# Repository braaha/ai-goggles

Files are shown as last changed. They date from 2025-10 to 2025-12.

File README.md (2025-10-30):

AI Goggles to Understand Influences on Well-being with Life-changing Injury or Pathology

Team Members:

Team Member #1: Cooper Bush – Computer Science
Team Member #2: AJ Aneja – Mechanical Engineering
Team Member #3: Junho Ha – Mechanical Engineering
Team Member #4: Braah Mustafa – Computer Engineering

Fast-Forward Summary:

The prototype we developed is AI goggles to help monitor individuals with neurobehavioral injury. The goggles help us to understand factors in daily life that impact people recovering from spinal injury, strokes, and substance use. The glasses work by recording visual and audio data, and potentially eye tracking. Our prototypes record data through cameras and sensors attached to the frame. The data is then sent to a mobile app that securely transmits the data to a server that uses AI to analyze it.

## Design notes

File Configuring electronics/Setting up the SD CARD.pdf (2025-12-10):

How To Set Up the SD Card With Raspberry Pi Imager:

### 1. Download Raspberry Pi Imager

Go to this site and download Raspberry Pi Imager:

https://www.raspberrypi.com/software/

Install it like a regular app. Nothing special.

### 2. Put the SD Card in Your Laptop

Take the microSD card out of the Pi
put it into the SD card adapter/or sd card reader
then plug the adapter into your laptop.

If your laptop doesn’t have an SD slot, use a USB SD card reader.

### 3. Open Raspberry Pi Imager

When it opens you’ll see three options:

- Choose Device
- Choose OS
- Choose Storage

This is where you pick everything the Pi needs.

### 4. Choose the Device

Click “Choose Device” and select:

Raspberry Pi Zero 2 W

### 5. Choose the Operating System

Click “Choose OS” and pick:

Raspberry Pi OS Lite (32-bit)

This is the version without the desktop. That’s what we used for this project because it runs faster on the small Pi.

### 6. Choose the Storage

Click “Choose Storage” and select the SD card you plugged in.

Just double check you’re selecting the SD card and not another hard drive. (It will erase whatever you choose.)

### 7. Click “Next”

It will ask if you want to edit settings.

Click Yes.

### 8. Fill Out the Settings

This part matters.

A. Set the username and password

Use:

- Username: pi
- Password: (whatever you want)
B. Wi-Fi setup (optional but helpful)

Type in:

- Wi-Fi name
- Wi-Fi password
- Country

This makes the Pi auto-connect when it turns on.

C. Enable SSH (optional)

Turn on SSH if you want to connect to the Pi from your laptop later.

### 9. Click Save → Write

It will erase the SD card and reload the operating system.

When it finishes, eject the SD card like normal.

### 10. Put the SD Card Back Into the Pi

Now the Pi will boot as if it’s brand new.

After that, you still need to put the ai-goggles project folder back on the SD card. You can drag and drop it by plugging the SD card into your laptop again, or by plugging the Pi into your laptop and opening the Pi’s storage.

If something really messed up the Pi, re-imaging is usually the fastest way to fix it.

# If the Pi Won’t Connect to Wi-Fi

Sometimes the Wi-Fi just refuses to connect, and it’s not your fault. Here are things to check:

- Make sure the Wi-Fi you’re using has a normal password. If it makes you log in on a webpage after connecting, the Pi won’t work with that.
- Some networks need both a username and password (like campus or workplace Wi-Fi). The Pi can’t join those automatically.
- Check the Wi-Fi name (SSID). If it has spaces, weird symbols, emojis, or punctuation, the Pi might not like it. Even stuff like “!” or “#” can cause problems.
- Re-enter the Wi-Fi password in Raspberry Pi Imager. Typos happen way more than you’d think.
- When you filled out the Wi-Fi settings in Imager, make sure you chose the right country.
- If all else fails, try connecting the Pi to something simple like your phone’s hotspot just to see if it works.
- And if nothing fixes it… honestly just try re-imaging the SD card again.

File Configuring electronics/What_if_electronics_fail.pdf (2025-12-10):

# What To Do If Something Stops Working

This is just a simple guide to try before replacing any component. A lot of problems are small stuff like a loose wire or the Pi acting up.

## If the microphone stops working

Make sure the mic wires did't come loose from the Pi. They pop out easier than you think.

Check if the Pi even sees the mic:

arecord -l

Restart the Pi and try again, sometimes that actually fixes it.

Run the mic test script (test_mic.py) if you want to double check the audio setup. Also check the audio libraries because if one is missing it wont record at all.

If none of this helps the mic might actually be dead and you will probably need to replace it.

## If the camera stops working

First thing always check the ribbon cable. Make sure it's pushed in fully on both sides. Even a tiny bit loose will break it.

Look at the ribbon to see if it's bent too sharp or damaged. These cables are kinda sensitive.

Restart the Pi and try recording again.

Run the camera test script (test_camera.py). If that script errors out then the Pi is not detecting the camera so its usually the ribbon cable or the camera itself.

## If the Pi wont turn on

Make sure the battery actually has charge. Sometimes it looks plugged in but the battery is empty.

Try a different micro usb cable. Some cables only charge they dont do data and can mess stuff up.

Try powering the Pi from a wall outlet just to test it. If it turns on there then the battery or cable was the issue.

Take the SD card out and put it back in so its seated right.

If it still wont power on then the SD card might be corrupted and you prob need to re image it.

## If the Pi freezes or wont record

Restart the Pi (yeah I know but it works most of the time)

Check the SD card space. If it is full or close to full the recording scripts will freeze.

Try running the script again after a reboot.

Run a simple test script for camera or mic to see if those still work. If one of them fails that's the reason the recording freezes.

Sometimes the SD card is just slow or corrupted and needs a re image.

## If WiFi wont connect

Make sure the WiFi network uses a normal password. If it needs a username and password (like school wifi) the Pi cant join that by default.

Check the WiFi name. If it has weird symbols or like spaces sometimes that causes issues.

Try typing the WiFi name and password again in Raspberry Pi Imager to make sure it wasn't just a typo.

Make sure the correct country was picked when setting up wifi in the imager. If it's set wrong the wifi wont work at all.

Try connecting the Pi to a hotspot from your phone just to see if the Pi wifi is working.

If it still wont connect you can re image the SD card and set the wifi again.

## If SD card errors happen

Copy anything important off the card onto your laptop first.

Re image the SD card using Raspberry Pi Imager.

Put the project folder back onto the SD card after imaging.

Put the SD card back into the Pi and try again.

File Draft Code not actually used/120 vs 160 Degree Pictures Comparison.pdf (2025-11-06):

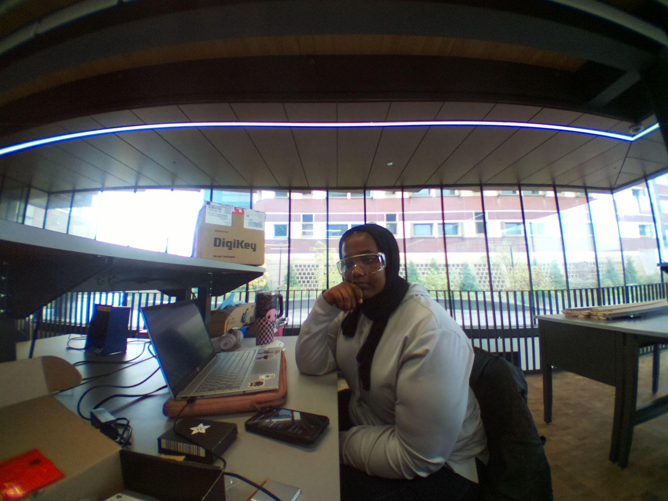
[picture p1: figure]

Zero Spy Camera for Raspberry Pi - 160 Degree

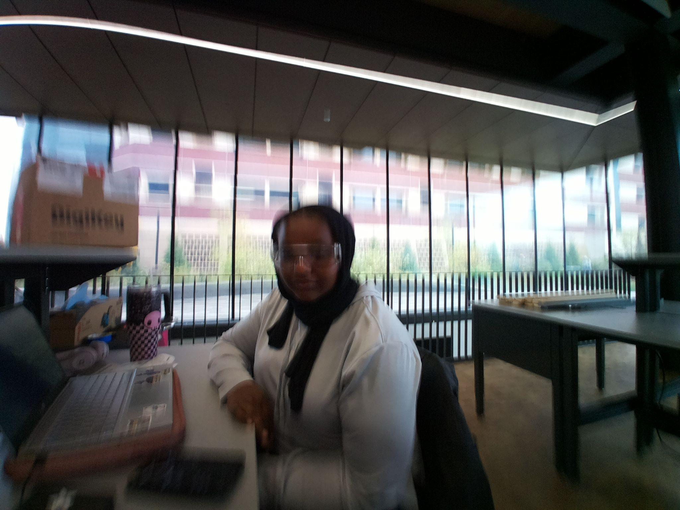
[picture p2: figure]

Zero Spy Camera for Raspberry Pi - 120 Degree

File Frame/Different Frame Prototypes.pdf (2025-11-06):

Appendix A - Concept Generation Models

Drawing Titles | Drawings

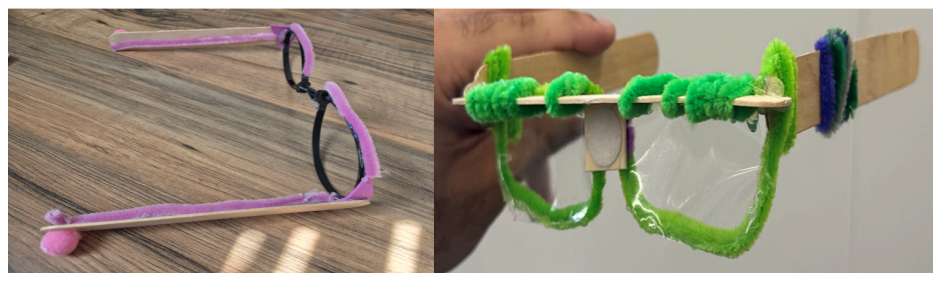
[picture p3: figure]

Prototype 1 (P1)

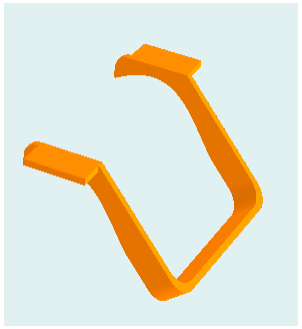
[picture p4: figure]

Prototype 2 (P2)

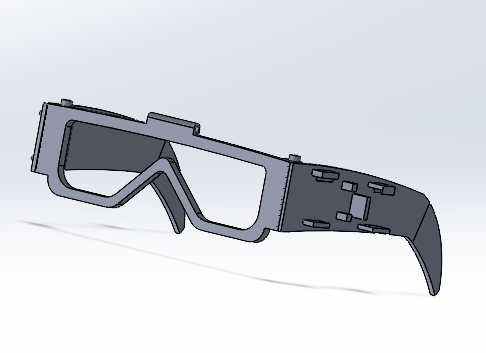
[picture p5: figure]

Prototype 3 (P3)

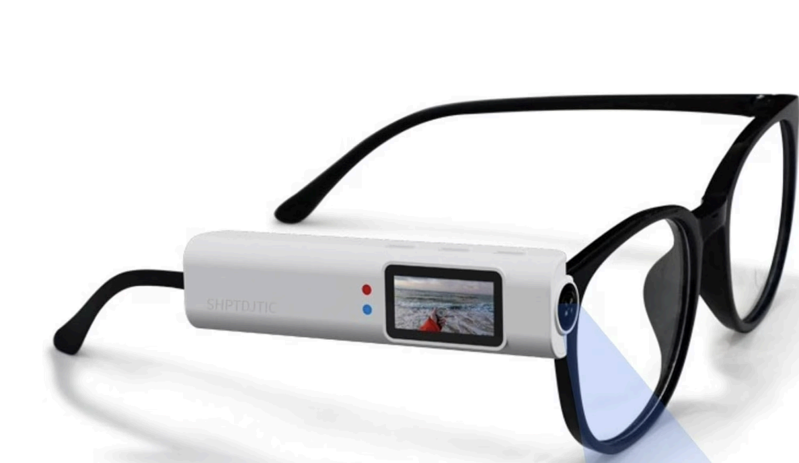
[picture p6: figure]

Reference Prototype (RP)

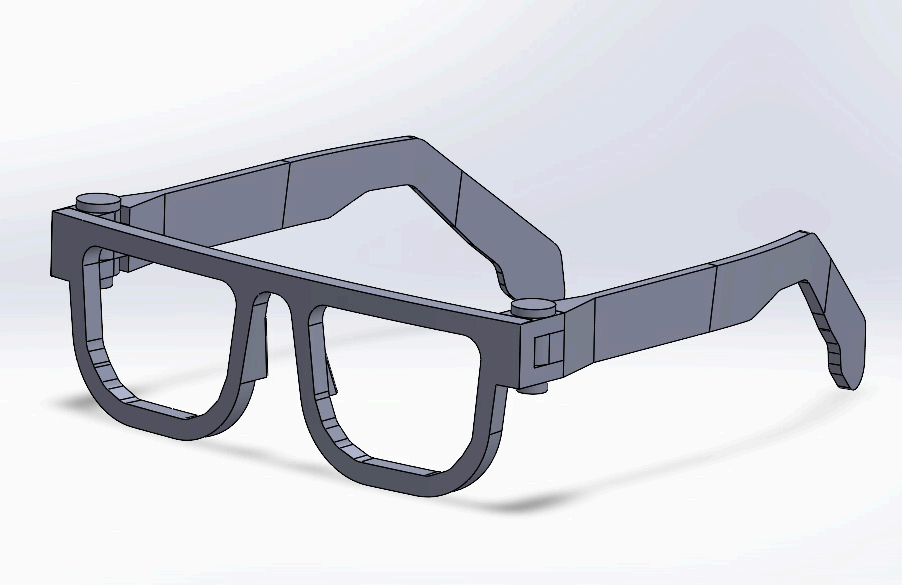
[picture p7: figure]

Prototype 4 (P4)

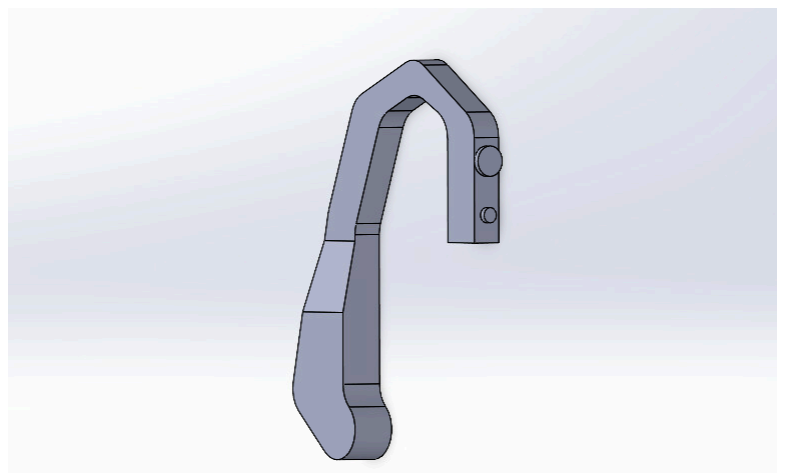
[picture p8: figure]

Prototype 5 (P5)

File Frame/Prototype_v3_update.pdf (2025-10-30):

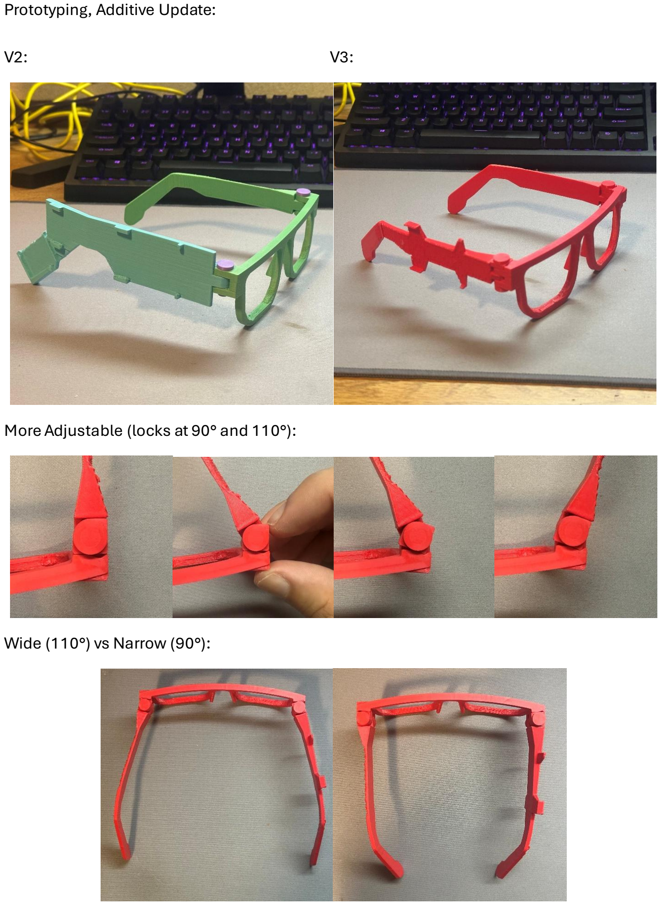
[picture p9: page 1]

Prototyping, Additive Update:

V2: | V3:

More Adjustable (locks at 90° and 110°):

Wide (110°) vs Narrow (90°):

Even weight distribution, more comfortable, stronger and more durable from print speed reduction, increased infill, and more optimized print orientation.

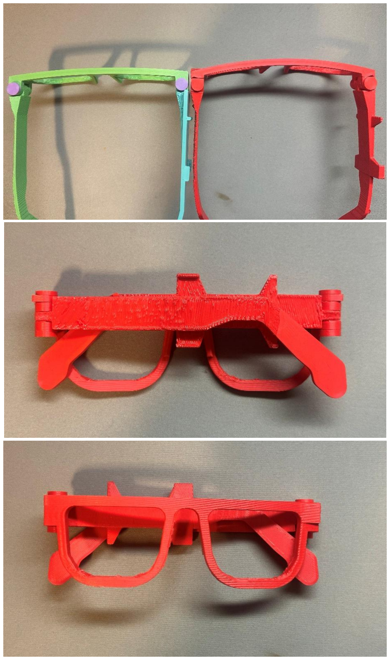
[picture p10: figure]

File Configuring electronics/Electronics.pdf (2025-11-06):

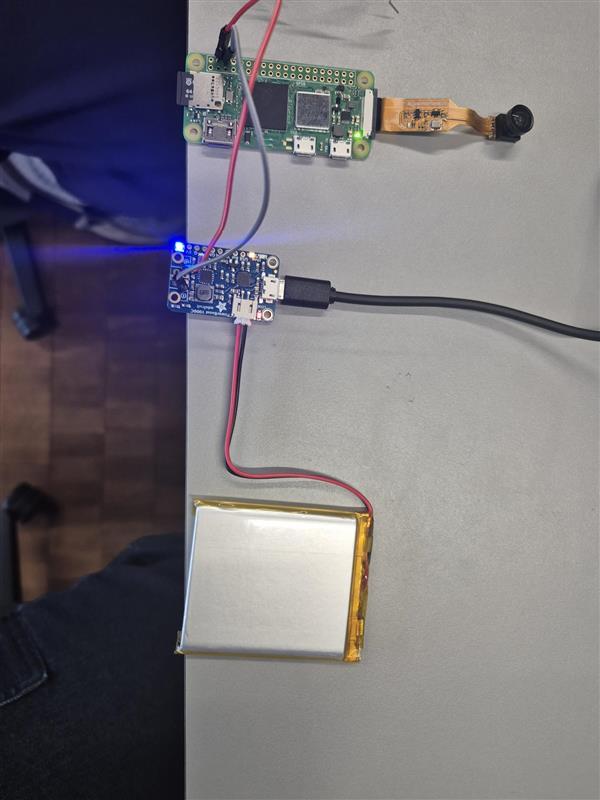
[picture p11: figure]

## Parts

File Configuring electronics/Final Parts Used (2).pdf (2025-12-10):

# Final Parts Used

## Microcontroller

Raspberry Pi Zero 2W (non-soldered header version)

- Cost: $19.05
- Product ID: 5291
- Website: adafruit.com
- Link: https://www.adafruit.com/product/5291

## Microphone

Adafruit I2S MEMS Microphone Breakout – SPH0645LM4H

- Cost: $6.95
- Product ID: 3421
- Website: adafruit.com
- Link: https://www.adafruit.com/product/3421

## Camera

Zero Spy Camera for Raspberry Pi Zero – 160 Degree FOV

- Cost: $24.95
- Product ID: 5390
- Website: adafruit.com
- Link: https://www.adafruit.com/product/5390

## Battery

Lithium Ion Battery Pack – 3.7V 6600mAh

- Cost: $24.50
- Product ID: 353
- Website: adafruit.com
- Link: https://www.adafruit.com/product/353

## Power Module

PowerBoost 1000 Charger – Rechargeable 5V LiPo USB Boost @ 1A (1000C)

- Cost: $19.95
- Product ID: 2465
- Website: adafruit.com
- Link: https://www.adafruit.com/product/2465

## Storage:

Official Raspberry Pi A2-Class microSD Card - 64GB Blank

- Cost: $12.79
- Product ID: 6011
- Website: adafruit.com
- Link: https://www.adafruit.com/product/6011

A cloud storage such as AWS account

## 3-D printed Wearables

## Glass frames

- Reference CAD Mode

## Battery Case

- Reference CAD Model

## Additional Materials Needed

- Micro SD Card Reader
- Type A to Micro-USB cable (short, around 3-6 inches)
- Type A to Micro-USB cable (2–3 feet, this is the cable that will be going from the glasses to the battery case, you could adjust the length as needed to fit each individual comfortably)

- Micro-USB charger to charge the device
- Clear Adhesive Squares

Price: $0.95

Website adafruit.com

Link: https://www.adafruit.com/product/4813

Product ID: 4813

- Electronics friendly glue
- Wires
- Soldering iron and solder

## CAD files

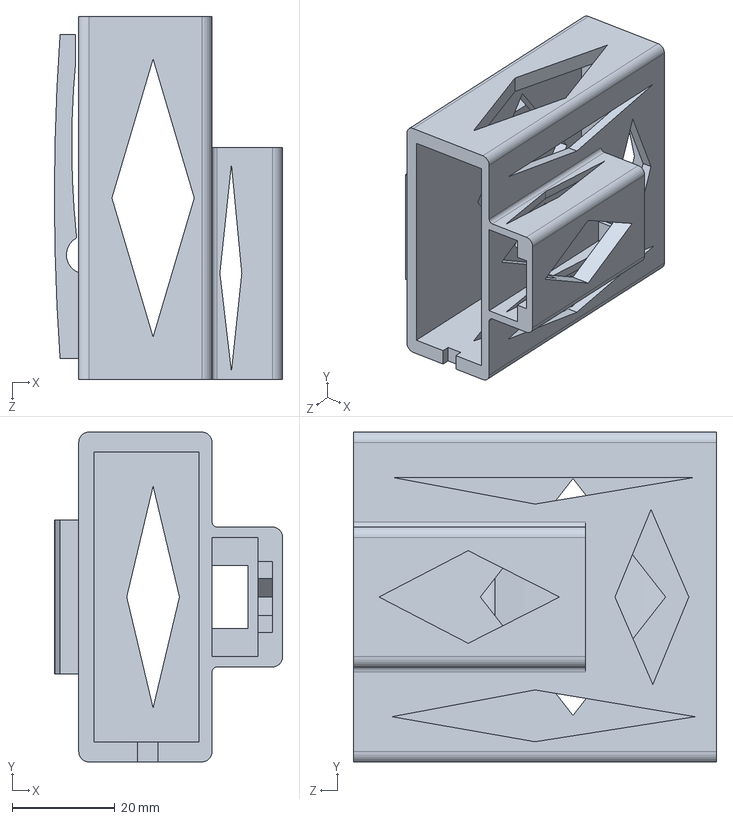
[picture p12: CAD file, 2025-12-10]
CAD Files/edsgn 460W Battery Case_final.SLDPRT
44.3 x 64.1 x 70.6 mm

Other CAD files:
CAD Files/_$Assem2.SLDASM
CAD Files/_$Assem1.SLDASM

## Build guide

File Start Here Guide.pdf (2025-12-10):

# Start Here Guide

Hi, if you are reading this you are probably taking over the project or trying to rebuild the glasses from scratch. This guide just explains where everything is in the repo so you don’t have to click around and guess.

## 1. What this project :

The device is a pair of 3D printed glasses with a Raspberry Pi Zero 2 W inside, a wide angle spy camera in the front, and an I2S mic on the top slit of the frame. The Pi records audio and video, and depending on the script used, it can save the files locally or send them to a server. The project also includes code for an iphone application in swift.

Everything you need to rebuild, test, or fix the device is in this repo.

## 2. Where all the important files are

Here’s the repo layout and what each folder is for:

AV_testing_scripts

This folder has the simple test scripts:

- test_camera.py
- test_mic.py

Run these if you want to check that the camera or mic still works before doing anything else.

CAD Files / CAD_Files_guide

This folder has the 3D model references.
This is helpful if you want to reprint frames, battery cases, or modify the design.

Configuring electronics

This folder has the docs you need when wiring stuff or placing components inside the glasses:

- Final Parts Used.pdf
- How to replicate.pdf
(this is the hardware replication guide for placing everything inside the frame)
- Setting up the SD CARD.pdf
(explains how to image the SD card and configure things using Raspberry Pi Imager)
- What_if_electronics_fail.pdf
(troubleshooting guide for if the mic, camera, Pi, WiFi, or SD card stop working)

Open these first if you're rebuilding or fixing hardware.

Frame

This folder has the 3D frame prototype PDFs:

- different frame versions
- the final frame update
These help you understand how the slits for the mic and camera are placed.

GlassesApp

This is the iPhone app code (Swift). Only needed if you want to change how the app connects or displays recordings.

GlassesFirmware

This holds the Python BLE server:

- glasses_ble_server.py
This is what lets the app talk to the Pi through Bluetooth.

setting up software

This is where new setup documents. This folder is useful for:

- how to provision a new device
- how to set up the server connection
- required libraries

## 3. If you want to rebuild the hardware

Start with:

- Final Parts Used.pdf
- How to replicate.pdf

These explain what parts we actually used and how the Pi, camera, mic, battery, and PowerBoost all fit inside the glasses and battery case.

## 4. If you need to set up or reimage the Pi

Open:

- Setting up the SD CARD.pdf

This shows:

- how to use Raspberry Pi Imager
- how to set the WiFi name and password
- how to enable SSH
- how to write the OS to the SD card

Once my partner adds the rest, check the setting up software folder for server setup and required libraries.

## 5. If you need to test the mic or camera

Go to AV_testing_scripts and run:

- test_camera.py
- test_mic.py

If these fail, open What_if_electronics_fail.pdf for the basic checks.

## 6. If something break

Open:

- What_if_electronics_fail.pdf

It covers:

- mic not detected
- camera not working
- Pi not powering on
- WiFi not connecting

- SD card corrupted
- Pi freezing

Most issues can be fixed without replacing parts.

## 7. Recommended order if you are starting fresh

1. Read Final Parts Used
2. Read How to replicate
3. Build the hardware
4. Use Setting up the SD CARD to image and configure the Pi
5. Check setting up software for server and library setup (once added)
6. Test with test_camera.py and test_mic.py
7. Try the full audio video scripts
8. Use What_if_electronics_fail if needed

## 8. Who this guide is for

Anyone rebuilding the device, testing it, or trying to understand what is what.

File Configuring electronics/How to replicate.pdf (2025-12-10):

# Hardware Setup Guide

Before you start, make sure the battery is charged. You should always charge it using the PowerBoost USB port because the PowerBoost is what handles charging safely. Do not charge the battery directly. Just plug it into the PowerBoost and wait until it is full.

Also, try not to use super long wires. It honestly just makes everything harder to fit inside the glasses. Medium wires around 4 to 5 inches work the best. Long enough to move stuff around but not so long that everything becomes a mess inside the frame.

## 1. Put the SD card into the Pi

Take your imaged SD card and slide it into the Raspberry Pi Zero slot. Make sure it clicks so it is actually in there.

## 2. Solder everything that needs wires

Do all the soldering before you try fitting things into the glasses because once everything is inside it gets annoying to fix.

Solder the microphone wires

Assuming you are holding the Raspberry Pi so the SD card slot is facing down, the pins are arranged in 20 pairs going straight down. The numbering starts at the top left with pins 1 and 2. Right under that is 3 and 4, then 5 and 6, and it keeps going like that all the way to the bottom. The left column is all the odd numbers and the right column is all the even numbers. The I2S mic has 6 pads. Solder wires to each pad, then the other end of each wire goes to the Pi like this:

Mic Pin | Pi Pin
3V | Pin 39
GND | Pin 32

BCLK | Pin 29
Dout | Pin 3
LRCL | Pin 6
SEL | Pin 27

When you solder the mic, try making it so the mic head points the opposite direction from the Pi ports. This makes it easier to guide it through the top slit in the glasses later.

Solder the PowerBoost USB port

The small USB port that comes with the PowerBoost needs to be soldered to the PowerBoost board so you can power the Pi.

## 3. Place the Raspberry Pi into the glasses

Slide the Raspberry Pi into the bigger arm of the glasses. The USB and HDMI ports should be facing down toward the bottom opening. The camera connector on the Pi should be facing the front slit because that is where the camera will go.

Do not glue anything permanently yet. Just place it so you can line everything up.

## 4. Set up the camera

Take the camera ribbon and connect it to the Pi camera port. Metal contacts on the ribbon face inward toward the Pi.

Push the camera module through the front slit so the camera stays outside the frame at eye level and the ribbon stays inside the arm. You can glue the camera lightly to the front once it is lined up.

## 5. Set up the microphone

Feed the mic wires through the top opening of the glasses arm. The mic sits outside the frame near the top slit so it can pick up audio better. Glue it gently to the side once you are sure the wiring is correct.

Inside the arm, lay the wires as flat as you can. Do not bend the ribbon cable sharply.

## 6. Put the battery and PowerBoost in the battery case

Put the big blue battery into the larger side of the 3D printed case. The PowerBoost goes into the smaller section.

The diamond shaped holes in the case let you run cables out.

Connect the battery to the PowerBoost using the JST connector port that is already in the power boost.

## 7. Connect power

Use a micro USB cable to connect the PowerBoost output to the Raspberry Pi power port. This is the main power line for the whole device.

Most people use the long cable so they can clip the battery case to their shirt or belt and keep the glasses light but you could change the size of this cable to wear it differently and to custom fit different individuals.

## 8. Final positioning inside the glasses

Once everything is wired:

- Camera is coming out of the front slit
- Mic is coming out of the top slit
- Raspberry Pi sits in the thicker arm
- Wires run neatly inside without crazy bends
- Ribbon cable is not twisted
- Power comes from the battery case through the long micro USB cable

Use adhesive squares or a small amount of electronics friendly glue to keep things in place. Do not cover Pi ports or the SD card slot because you might need them later.

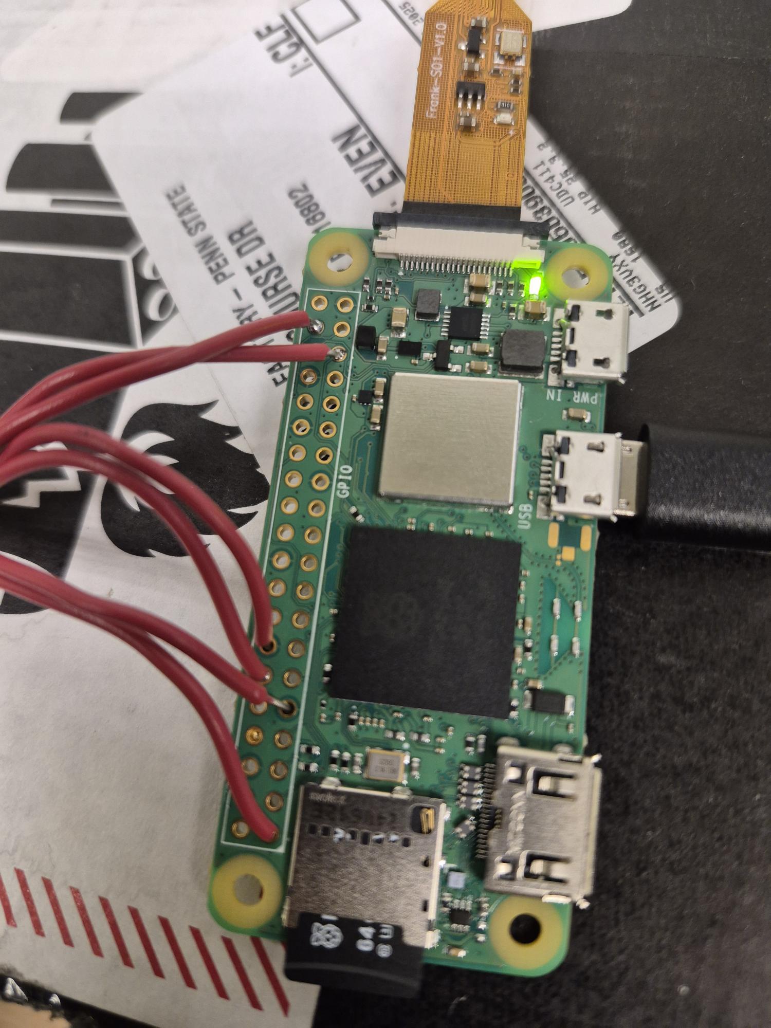
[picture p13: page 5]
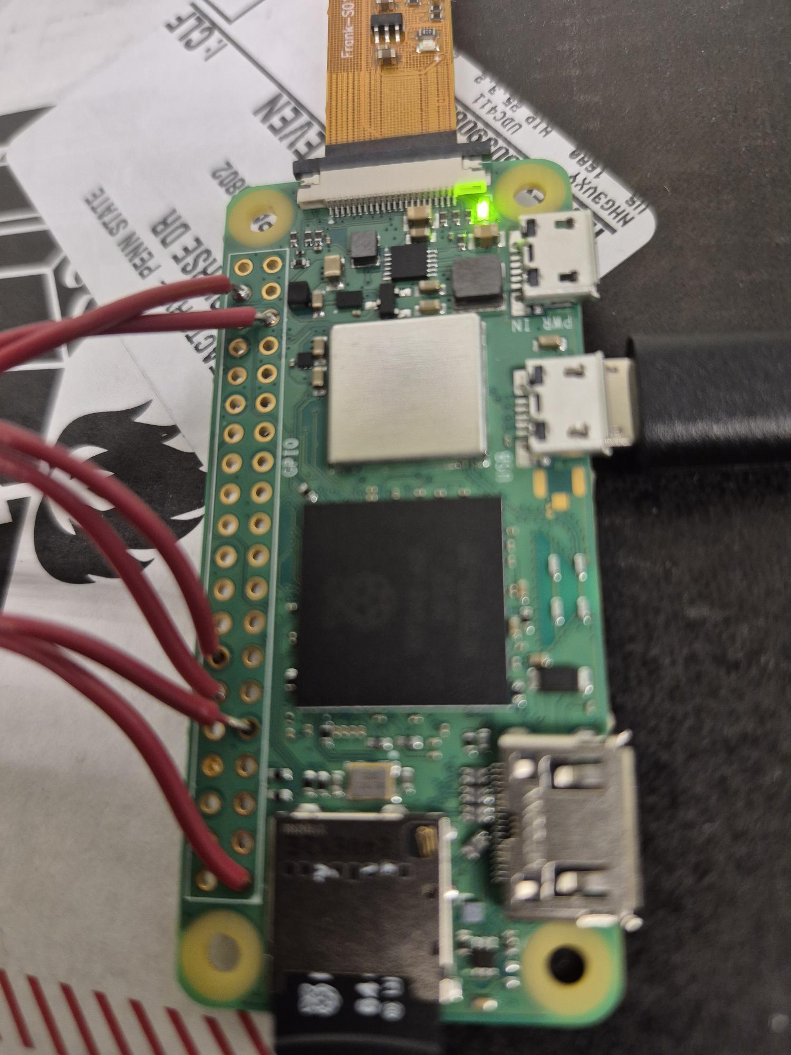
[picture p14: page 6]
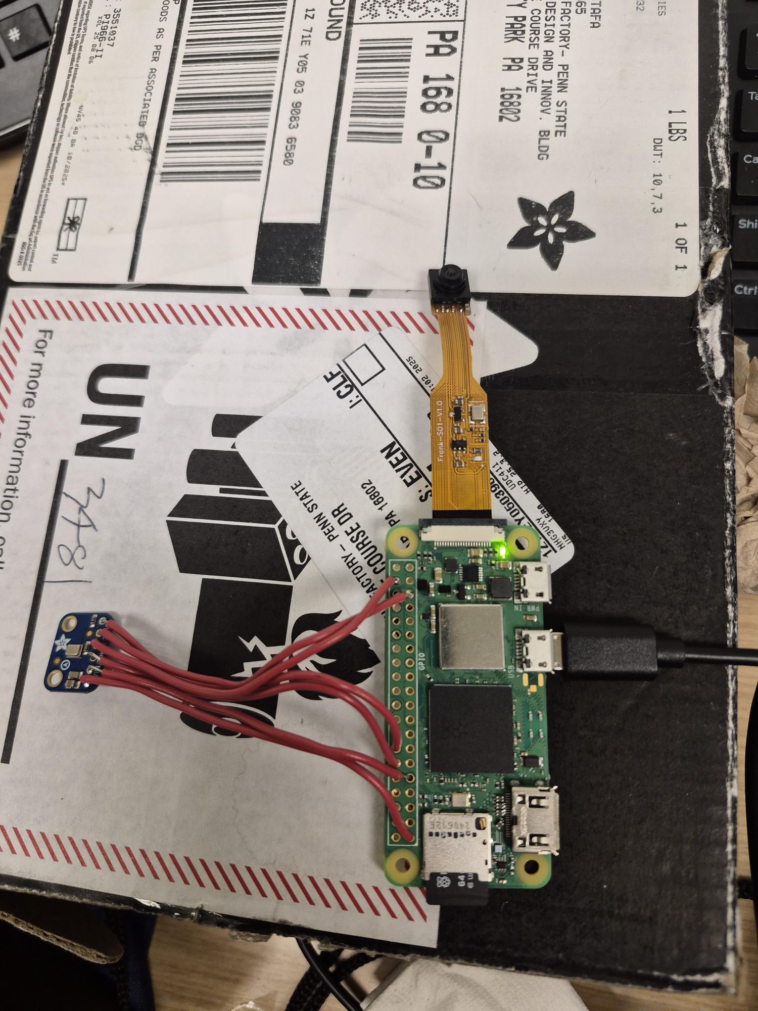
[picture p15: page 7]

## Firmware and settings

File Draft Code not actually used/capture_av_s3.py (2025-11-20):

#!/usr/bin/env python3
import argparse
import subprocess
import sys
import time
from datetime import datetime
from pathlib import Path

import boto3
from botocore.exceptions import BotoCoreError, ClientError

from picamera2 import Picamera2
from picamera2.encoders import H264Encoder
from picamera2.outputs import FileOutput


def record_audio(audio_path: Path, seconds: int, device: str = "plughw:1,0"):
    """
    Record audio using arecord for the specified number of seconds.
    """
    cmd = [
        "arecord",
        "-D", device,
        "-f", "S16_LE",
        "-r", "44100",
        "-c", "2",
        "-d", str(seconds),
        str(audio_path),
    ]
    print(f"[AUDIO] Running audio command: {' '.join(cmd)}")
    sys.stdout.flush()
    # Use Popen so audio can run while video records
    return subprocess.Popen(cmd)


def record_video(video_path: Path, seconds: int, width: int = 1280, height: int = 720, fps: int = 30):
    """
    Record video using Picamera2 (libcamera) to an .h264 file.
    """
    print(f"[VIDEO] Starting recording to {video_path.name} ({width}x{height}, {fps} fps)")
    sys.stdout.flush()

    picam2 = Picamera2()
    video_config = picam2.create_video_configuration(
        main={"size": (width, height)}
    )
    picam2.configure(video_config)

    encoder = H264Encoder()
    output = FileOutput(str(video_path))

    picam2.start_recording(encoder, output)
    time.sleep(seconds)
    picam2.stop_recording()

    print("[VIDEO] Stopping recording")
    sys.stdout.flush()


def merge_av_to_mp4(video_path: Path, audio_path: Path, final_path: Path, fps: int = 30):
    """
    Use ffmpeg to merge the .h264 video and .wav audio into an .mp4 file.
    This follows the same pattern that already worked for you.
    """
    cmd = [
        "ffmpeg",
        "-y",
        "-r", str(fps),
        "-i", str(video_path),
        "-i", str(audio_path),
        "-c:v", "libx264",
        "-preset", "veryfast",
        "-crf", "23",
        "-c:a", "aac",
        "-shortest",
        str(final_path),
    ]
    print(f"[FFMPEG] Running: {' '.join(cmd)}")
    sys.stdout.flush()

    subprocess.run(cmd, check=True)
    print(f"[FFMPEG] MP4 created: {final_path}")
    sys.stdout.flush()


def upload_to_s3(file_path: Path, bucket: str, key: str, region: str):
    """
    Upload the given file to S3.
    """
    print(f"[S3] Uploading to bucket='{bucket}', key='{key}', region='{region}'")
    sys.stdout.flush()

    s3 = boto3.client("s3", region_name=region)

    try:
        s3.upload_file(str(file_path), bucket, key)
    except (BotoCoreError, ClientError) as e:
        print("[S3] Upload failed with error:")
        print(e)
        raise

    print("[S3] Upload successful.")
    sys.stdout.flush()


def parse_args():
    parser = argparse.ArgumentParser(
        description="Record audio+video (arecord + Picamera2), merge with ffmpeg, and upload MP4 to S3."
    )
    parser.add_argument(
        "--seconds",
        type=int,
        default=5,
        help="Recording duration in seconds (default: 5)",
    )
    parser.add_argument(
        "--bucket",
        required=True,
        help="S3 bucket name (you have: ai-goggles-recordings)",
    )
    parser.add_argument(
        "--prefix",
        default="ai-goggles",
        help="S3 key prefix (default: ai-goggles)",
    )
    parser.add_argument(
        "--device-id",
        default="pi-goggles-1",
        help="Logical device id to include in the key path",
    )
    parser.add_argument(
        "--region",
        default="us-east-2",
        help="AWS region for S3 client (default: us-east-2)",
    )
    parser.add_argument(
        "--audio-device",
        default="plughw:1,0",
        help="ALSA device for arecord (default: plughw:1,0)",
    )
    return parser.parse_args()


def main():
    args = parse_args()
    seconds = args.seconds

    # Timestamp for filenames
    ts = datetime.now().strftime("%Y%m%d_%H%M%S")

    video_path = Path(f"video_{ts}.h264")
    audio_path = Path(f"audio_{ts}.wav")
    final_path = Path(f"final_{ts}.mp4")

    print("==========================================")
    print(" Starting capture")
    print(f"  Seconds:     {seconds}")
    print(f"  Resolution:  1280x720")
    print(f"  FPS:         30")
    print(f"  Audio rate:  44100 Hz")
    print(f"  Audio ch:    2")
    print(f"  Device:      {args.audio_device}")
    print("==========================================")
    sys.stdout.flush()

    try:
        # Start audio first (like your working flow), then video
        audio_proc = record_audio(audio_path, seconds, device=args.audio_device)
        record_video(video_path, seconds, width=1280, height=720, fps=30)

        # Wait for audio to finish
        audio_ret = audio_proc.wait()
        if audio_ret != 0:
            raise RuntimeError(f"arecord failed with exit code {audio_ret}")

        print(f"[AUDIO] Audio recorded to: {audio_path}")
        print(f"[INFO] Saved video: {video_path.resolve()}")
        print(f"[INFO] Saved audio: {audio_path.resolve()}")
        sys.stdout.flush()

        # Merge into MP4
        merge_av_to_mp4(video_path, audio_path, final_path, fps=30)

        print("==========================================")
        print(" DONE")
        print(f" Video file: {video_path.name}")
        print(f" Audio file: {audio_path.name}")
        print(f" Final MP4:  {final_path.name}")
        print("==========================================")
        sys.stdout.flush()

    except Exception as e:
        print("Error during recording or merging:")
        print(e)
        sys.stdout.flush()
        sys.exit(1)

    # Build S3 key: prefix/device-id/filename
    s3_key = f"{args.prefix.rstrip('/')}/{args.device_id}/{final_path.name}"

    try:
        upload_to_s3(final_path, args.bucket, s3_key, args.region)
    except Exception as e:
        print("S3 upload failed:")
        print(e)
        sys.exit(2)


if __name__ == "__main__":
    main()

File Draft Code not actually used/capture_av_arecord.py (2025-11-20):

#!/usr/bin/env python3


import argparse
import subprocess
import threading
import time
from datetime import datetime
from pathlib import Path

from picamera2 import Picamera2, encoders


def record_video(
    path: Path,
    seconds: int,
    width: int,
    height: int,
    bitrate: int,
    fps: int,
) -> None:
 

    picam2 = Picamera2()

    config = picam2.create_video_configuration(
        main={"size": (width, height)},
        controls={"FrameDurationLimits": (int(1e6 / fps), int(1e6 / fps))},
    )
    picam2.configure(config)

    encoder = encoders.H264Encoder(bitrate=bitrate)

    print(f"[VIDEO] Starting recording to {path} ({width}x{height}, {fps} fps)")
    picam2.start_recording(encoder, str(path))

    try:
        time.sleep(seconds)
    finally:
        print("[VIDEO] Stopping recording")
        picam2.stop_recording()
        picam2.close()


def record_audio_arecord(
    path: Path,
    seconds: int,
    samplerate: int,
    channels: int,
    device: str,
) -> None:


    cmd = [
        "arecord",
        "-D",
        device,
        "-f",
        "S16_LE",
        "-r",
        str(samplerate),
        "-c",
        str(channels),
        "-d",
        str(seconds),
        str(path),
    ]

    print("[AUDIO] Running audio command:", " ".join(cmd))
    result = subprocess.run(cmd, capture_output=True, text=True)

    if result.returncode != 0:
        print("[AUDIO] arecord FAILED")
        print(result.stderr)
        raise RuntimeError("arecord failed")

    print(f"[AUDIO] Audio recorded to: {path}")


def make_mp4(
    video_path: Path,
    audio_path: Path,
    output_path: Path,
    fps: int,
) -> None:


    cmd = [
        "ffmpeg",
        "-y",
        "-r",
        str(fps),              # input frame rate hint for raw H.264
        "-i",
        str(video_path),
        "-i",
        str(audio_path),
        "-c:v",
        "libx264",
        "-preset",
        "veryfast",
        "-crf",
        "23",
        "-c:a",
        "aac",
        "-shortest",
        str(output_path),
    ]

    print("[FFMPEG] Running:", " ".join(cmd))
    result = subprocess.run(cmd, capture_output=True, text=True)

    if result.returncode != 0:
        print("[FFMPEG] ffmpeg FAILED")
        print(result.stderr)
        raise RuntimeError("ffmpeg failed")

    print(f"[FFMPEG] MP4 created: {output_path}")


def parse_args() -> argparse.Namespace:
    parser = argparse.ArgumentParser(
        description="Record Pi camera video + Google Voice HAT audio into an MP4."
    )
    parser.add_argument("--seconds", type=int, default=5, help="Recording length in seconds")
    parser.add_argument("--width", type=int, default=1280, help="Video width")
    parser.add_argument("--height", type=int, default=720, help="Video height")
    parser.add_argument("--bitrate", type=int, default=10_000_000, help="Video bitrate (bits per second)")
    parser.add_argument("--samplerate", type=int, default=44100, help="Audio sample rate")
    parser.add_argument("--channels", type=int, default=2, help="Audio channels (2 = stereo)")
    parser.add_argument("--fps", type=int, default=30, help="Video frames per second")
    parser.add_argument(
        "--arecord-device",
        type=str,
        default="plughw:1,0",
        help="ALSA device string for arecord (e.g., plughw:1,0 for Google Voice HAT)",
    )
    return parser.parse_args()


def main() -> None:
    args = parse_args()

    ts = datetime.now().strftime("%Y%m%d_%H%M%S")
    video_path = Path(f"video_{ts}.h264")
    audio_path = Path(f"audio_{ts}.wav")
    final_path = Path(f"final_{ts}.mp4")

    print("==========================================")
    print(" Starting capture")
    print(f"  Seconds:     {args.seconds}")
    print(f"  Resolution:  {args.width}x{args.height}")
    print(f"  FPS:         {args.fps}")
    print(f"  Audio rate:  {args.samplerate} Hz")
    print(f"  Audio ch:    {args.channels}")
    print(f"  Device:      {args.arecord_device}")
    print("==========================================")

    # Run audio and video in parallel so they overlap
    audio_thread = threading.Thread(
        target=record_audio_arecord,
        args=(
            audio_path,
            args.seconds,
            args.samplerate,
            args.channels,
            args.arecord_device,
        ),
        daemon=True,
    )

    audio_thread.start()
    record_video(
        video_path,
        args.seconds,
        args.width,
        args.height,
        args.bitrate,
        args.fps,
    )
    audio_thread.join()

    # Sanity check: files must exist
    if not audio_path.exists():
        print("[ERROR] Audio file was not created. Aborting.")
        return
    if not video_path.exists():
        print("[ERROR] Video file was not created. Aborting.")
        return

    print(f"[INFO] Saved video: {video_path.resolve()}")
    print(f"[INFO] Saved audio: {audio_path.resolve()}")

    # Make MP4
    make_mp4(video_path, audio_path, final_path, args.fps)

    print("==========================================")
    print(" DONE")
    print(f" Video file: {video_path.name}")
    print(f" Audio file: {audio_path.name}")
    print(f" Final MP4:  {final_path.name}")
    print("==========================================")


if __name__ == "__main__":
    main()

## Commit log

2025-10-14 Add starter camera/mic tests and faces script
2025-10-30 Prototype Pictures
2025-12-10 EDSGN 460W Battery Case(FInal) CAD Model
    [edsgn 460W Battery Case_final.SLDPRT]
